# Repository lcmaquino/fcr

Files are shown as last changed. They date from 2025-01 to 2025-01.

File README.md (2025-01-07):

## Description

The Fenix Reballing Controller (FCR) software controls the temperature of two heating devices for preheating electronic boards or reballing BGA components. Examples of heating devices include an electric grill or an electric resistor. Due to the high electrical current required to power these devices, they should be activated via a mechanical relay or a solid-state relay.

The FCR consists of an electronic circuit with the [Raspberry Pi Pico](https://projects.raspberrypi.org/en/projects/getting-started-with-the-pico) microcontroller and a set of codes written for [MicroPython](https://www.micropython.org/).

## Assembly and Installation

  - Assemble the electronic circuit according to the schematic diagram: [fenix-controlador-de-ressolda.pdf](https://github.com/lcmaquino/fcr/tree/main/pcb/fenix-controlador-de-ressolda.pdf). Also, see the [simple wiring diagram](assets/fcr-simple-wiring.png);
  - Connect the relay input pins to the connectors indicated in the diagram by `OUT1` and `OUT2`;
  - Connect the relay output pins to the heating devices;
  - Connect the HD44780 LCD 16×02, MAX6675, and Keyes_AD_Key modules to their respective connectors indicated in the diagram;
  - Install the [MicroPython firmware](https://projects.raspberrypi.org/en/projects/getting-started-with-the-pico/3) on the Raspberry Pi Pico;
  - Use your preferred IDE to copy all files from the [`src`](https://github.com/lcmaquino/fcr/tree/main/src) directory to the Raspberry Pi Pico. (For example, you can use [Thonny](https://thonny.org/) or [Visual Studio Code](https://code.visualstudio.com/));
  - Power the electronic circuit with a 5V DC power supply with at least 500mA;

  The Keyes_AD_Key module has five tactile switches labeled SW1, SW2, SW3, SW4, and SW5. The FCR maps these switches for menu navigation such that:

  - SW1 - moves the menu to the left;
  - SW2 - increases the value of the currently displayed option;
  - SW3 - decreases the value of the currently displayed option;
  - SW4 - moves the menu to the right;
  - SW5 - selects the current menu;

## Usage

  The FCR has three modes:
  - Preheater - for preheating an electronic board;
  - Reballing - for reballing BGA components;
  - Auto Tuning - to automatically calculate the coefficients used in the [PID](https://en.wikipedia.org/wiki/Proportional-integral-derivative_controller) control;

  All modes have a menu containing specific and general options.

  The general options are:
  - `Kp` - proportional coefficient of the PID control;
  - `Ki` - integral coefficient of the PID control;
  - `Kd` - derivative coefficient of the PID control;
  - `ap` - actuation period is the period (in seconds) at which the PID control is updated;
  - `Run` - execute the mode functions;
  - `Home` - return to the initial mode selection screen;

  See below the specific options for each mode.

### Preheater Mode

  The Preheater mode controls only one heating device that should be placed below the electronic board.

  In Preheater mode, the specific options are:
  - `SV` - Setpoint Variable is the temperature (in degrees Celsius) that the heating element should reach;
  - `d` - duration is the duration (in seconds) the mode should run;

### Reballing Mode

  The Reballing mode controls two heating devices, one of which should be placed below the electronic board and the other above it.

  In Reballing mode, the specific options are:
  - `PTN` - pattern is the temperature pattern (in degrees Celsius) that the heating devices should follow. Each pattern consists of up to five parts, each containing the `r`, `L`, and `d` options explained below;
  - `r` - rate is the rate of temperature change (in degrees Celsius per second);
  - `L` - limit is the temperature limit (in degrees Celsius) that should be reached;
  - `d` - duration is the duration (in seconds) that the temperature should remain at its limit `L`;

  Up to 10 temperature patterns can be configured. Here is an example configuration:
```
  PTN1
  | - r1: 0.86
  | - L1: 120.0
  | - d1: 60
  | - r2: 0.57
  | - L2: 180.0
  | - d2: 60
  | - r3: 0.29
  | - L3: 210.0
  | - d3: 60
  | - r4: 0.19
  | - L4: 227.0
  | - d4: 60
  | - r5: 0.0
  | - L5: 0.0
  | - d5: 0
```

  Note that in this example, the PTN1 pattern will have four active parts. The fifth part is all zeros and will be ignored by the FCR. The figure below represents this pattern.

  Image of the graph representing the PTN1 pattern

  In the first part of the pattern, the temperature should rise at a rate of `r1 = 0.86`°C/s until it reaches `L1 = 120`°C, staying at this temperature for `d1 = 60`s. In the second part, the temperature should rise at a rate of `r2 = 0.57`°C/s until it reaches `L2 = 180`°C, staying at this temperature for `d2 = 60`s. In the third part, the temperature should rise at a rate of `r3 = 0.29`°C/s until it reaches `L3 = 210`°C, staying at this temperature for `d3 = 60`s. Finally, in the fourth part, the temperature should rise at a rate of `r4 = 0.19`°C/s until it reaches `L4 = 227`°C, staying at this temperature for `d4 = 60`s.

### Auto Tuning

  The Auto Tuning mode analyzes the temperature data of the heating device below the electronic board to approximately calculate the `Kp`, `Ki`, and `Kd` coefficients of the PID controller.

  In Auto Tuning mode, the specific options are:
  - `SV` - Setpoint Variable is the temperature (in degrees Celsius) that the heating element should reach;
  - `d` - duration is the duration (in seconds) the mode should run;

## License

FCR is open-sourced software licensed under the [GPL v3.0 or later](https://github.com/lcmaquino/ccolab/blob/main/LICENSE).

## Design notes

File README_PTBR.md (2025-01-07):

## Descrição

O programa Fenix Controlador de Ressolda (FCR) controla a temperatura de dois
dispositivos de aquecimento para a realização de pré-aquecimento de placas 
eletrônicas ou para a ressoldagem de componentes BGA. Como exemplo de 
dispositivo de aquecimento pode-se citar uma churrasqueira elétrica ou 
uma resitência elétrica. Devido a alta corrente elétrica necessária para 
ligar esses dispositivos, eles devem ser acionados via um relê mecânico 
ou um relê de estado sólido.

O FCR é composto por um circuito eletrônico com o microcontrolador
[Raspberry Pi Pico](https://projects.raspberrypi.org/en/projects/getting-started-with-the-pico)
e por um conjunto de códigos escritos para [MicroPython](https://www.micropython.org/).

## Montagem e Instalação

  - Monte o circuito eletrônico conforme o diagrama esquemático:
  [fenix-controlador-de-ressolda.pdf](https://github.com/lcmaquino/fcr/tree/main/pcb/fenix-controlador-de-ressolda.pdf).
  Veja também o [diagrama simplificado](assets/fcr-simple-wiring.png) de ligação;
  - Conecte os pinos de entrada do relê nos conectores indicados no diagrama 
  por `OUT1` e `OUT2`;
  - Conecte os pinos de saída do relê nos dispositivos de aquecimento;
  - Conecte os módulos HD44780 LCD 16×02, MAX6675 e Keyes_AD_Key nos seus respectivos
    conectores indicados no diagrama;
  - Instale o [firmware do MicroPython](https://projects.raspberrypi.org/en/projects/getting-started-with-the-pico/3) 
  no Raspberry Pi Pico;
  - Utilize a sua IDE preferida para copiar todos os arquivos do diretório 
  [`src`](https://github.com/lcmaquino/fcr/tree/main/src) para o Raspberry Pi Pico.
  (Por exemplo, você pode usar o [Thonny](https://thonny.org/) ou o 
  [Visual Studio Code](https://code.visualstudio.com/));
  - Ligue o circuito eletrônico com uma fonte de alimentação de 5V DC e 
  pelo menos 500mA;

  O módulo Keyes_AD_Key possui cinco chaves tácteis rotuladas como SW1, SW2, 
  SW3, SW4 e SW5. O FCR faz o mapeamento dessas chaves para a navegação 
  dos menus de modo que:

  - SW1 - movimenta o menu para a esquerda;
  - SW2 - aumenta o valor da opção exibida no momento;
  - SW3 - diminui o valor da opção exibida no momento;
  - SW4 - movimenta o menu para a direita;
  - SW5 - seleciona o menu atual;

## Uso

  O FCR possui três modos:
  - Preheater - para realizar o pré-aquecimento de uma placa eletrônica;
  - Reballing - para realizar a ressolda de componentes BGA;
  - Auto Tuning - para calcular automaticamente os parâmetros usados no controle
  [PID](https://pt.wikipedia.org/wiki/Controlador_proporcional_integral_derivativo);

  Todos os modos possuem um menu que contém opções específicas e opções gerais.

  As opções gerais são:
  - `Kp` - coeficiente proporcional do controle PID;
  - `Ki` - coeficiente integral do controle PID;
  - `Kd` - coeficiente derivativo do controle PID;
  - `ap` - _actuation period_ é o período (em segundos) no qual o controle PID é atualizado;
  - `Run` - executar as funções do modo;
  - `Home` - voltar para a tela inicial de seleção de modo;

  Vide a seguir as opções específicas de cada modo.

### Modo Preheater

  O modo Preheater controla apenas um dispositivo de aquecimento que deve ser 
  posicionado abaixo da placa eletrônica.

  No modo Preheater as opções específicas são:
  - `SV` - _Setpoint Variable_ é a temperatura (em graus Celcius) que o 
    elemento de aquecimento deve atingir;
  - `d` - _duration_ é a duração (em segundos) que o modo deve ficar executando;

### Modo Reballing

  O modo Reballing controla dois dispositivos de aquecimento sendo que 
  um deles deve ser posicionado abaixo da placa eletrônica e o outro
  acima dela.

  No modo Reballing as opções específicas são:
  - `PTN` - _pattern_ é o padrão de temperatura (em graus Celcius) 
    que os dispositivos de aquecimento devem seguir. Cada padrão é composto por até cinco 
    partes, sendo que cada uma delas contém as opções `r`, `L` e `d` explicadas a seguir;
  - `r` - _rate_ é a taxa de variação da temperatura (em graus Celcius por segundo);
  - `L` - _limit_ é o valor limite que a temperatura (em graus Celcius) deve atingir;
  - `d` - _duration_ é a duração (em segundos) que a temperatura deve permanecer no seu limite `L`;

  É possível configurar até 10 padrões de temperatura. Veja um exemplo de configuração a seguir:
```
  PTN1
  | - r1: 0.86
  | - L1: 120.0
  | - d1: 60
  | - r2: 0.57
  | - L2: 180.0
  | - d2: 60
  | - r3: 0.29
  | - L3: 210.0
  | - d3: 60
  | - r4: 0.19
  | - L4: 227.0
  | - d4: 60
  | - r5: 0.0
  | - L5: 0.0
  | - d5: 0
```

  Note que nesse exemplo o padrão PTN1 terá quatro partes ativas. A quinta parte
  está toda nula e será ignorada pelo FCR. A figura a seguir representa esse padrão.

  Imagem do gráfico representando o padrão PTN1

  Na primeira parte do padrão a temperatura deverá
  subir com uma taxa de variação de `r1 = 0.86`°C/s até atingir `L1 = 120`°C, 
  ficando nessa temperatura por `d1 = 60`s. Na segunda parte a temperatura deverá
  subir com uma taxa de variação de `r2 = 0.57`°C/s até atingir `L2 = 180`°C, 
  ficando nessa temperatura por `d2 = 60`s. Já na terceira parte a temperatura 
  deverá subir com uma taxa de variação de `r3 = 0.29`°C/s até atingir `L3 = 210`°C, 
  ficando nessa temperatura por `d3 = 60`s. Por fim, na quarta parte a temperatura 
  deverá subir com uma taxa de variação de `r4 = 0.19`°C/s até atingir `L4 = 227`°C, 
  ficando nessa temperatura por `d4 = 60`s.

### Auto Tuning

  O modo Auto Tuning analisa os dados de temperatura do dispostivo de aquecimento 
  abaixo da placa eletrônica para calcular de modo aproximado os coeficientes
  `Kp`, `Ki` e `Kd` do controlador PID.

  No modo Auto Tuning as opções específicas são:
  - `SV` - _Setpoint Variable_ é a temperatura (em graus Celcius) que o 
    elemento de aquecimento deve atingir;
  - `d` - _duration_ é a duração (em segundos) que o modo deve ficar executando;

## Licença

FCR é um programa de código aberto sob a licença [GPL v3.0 ou posterior](https://github.com/lcmaquino/ccolab/blob/main/LICENSE).

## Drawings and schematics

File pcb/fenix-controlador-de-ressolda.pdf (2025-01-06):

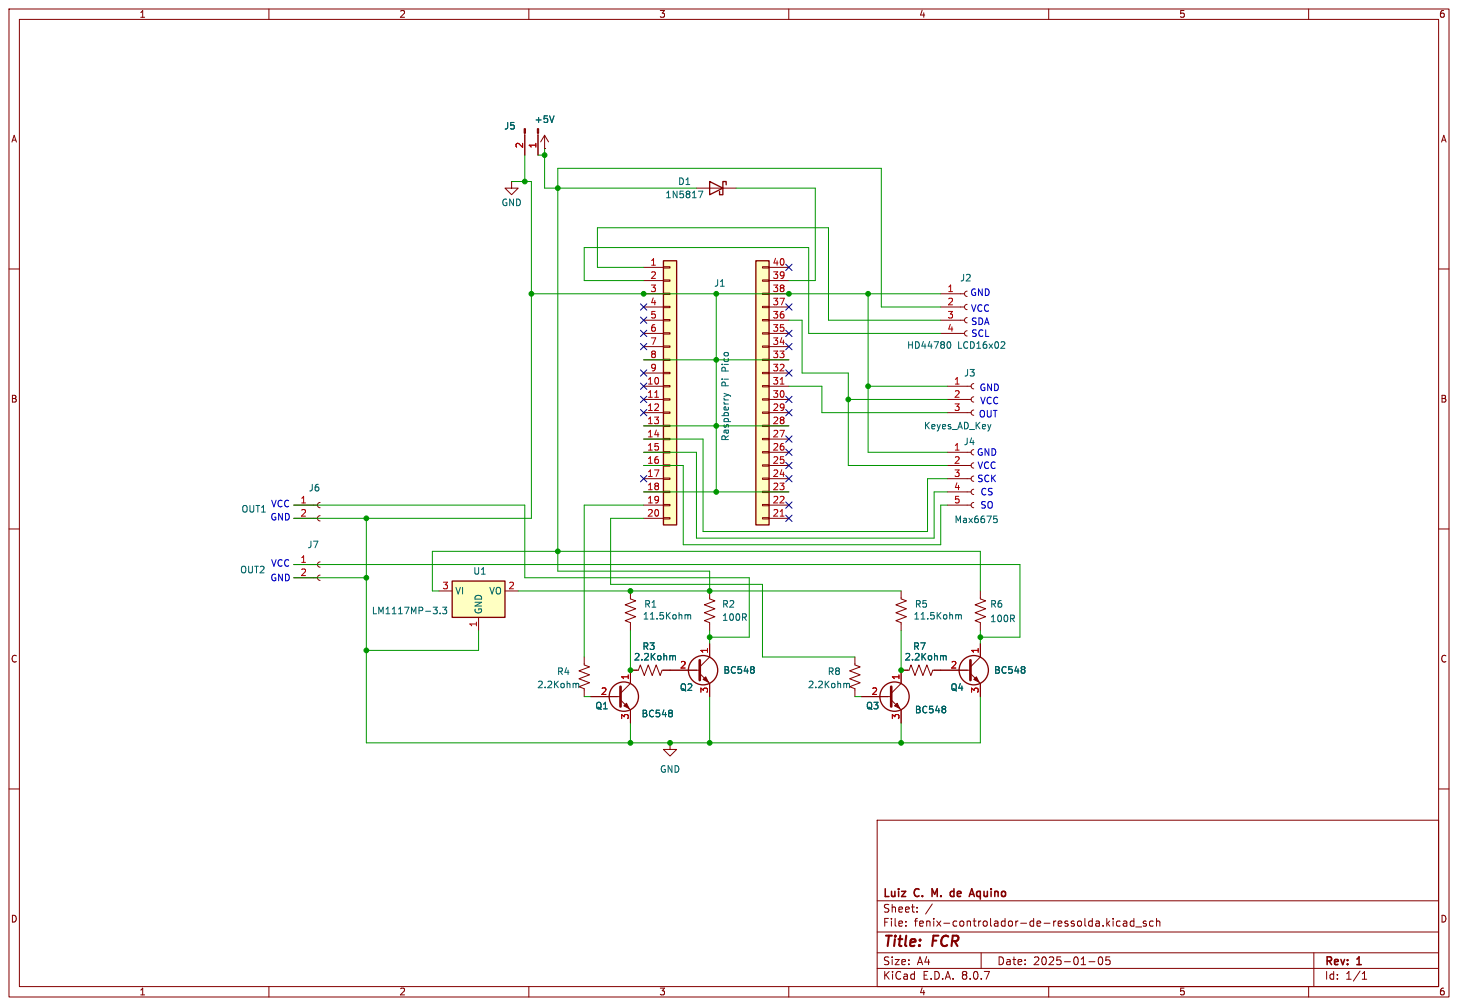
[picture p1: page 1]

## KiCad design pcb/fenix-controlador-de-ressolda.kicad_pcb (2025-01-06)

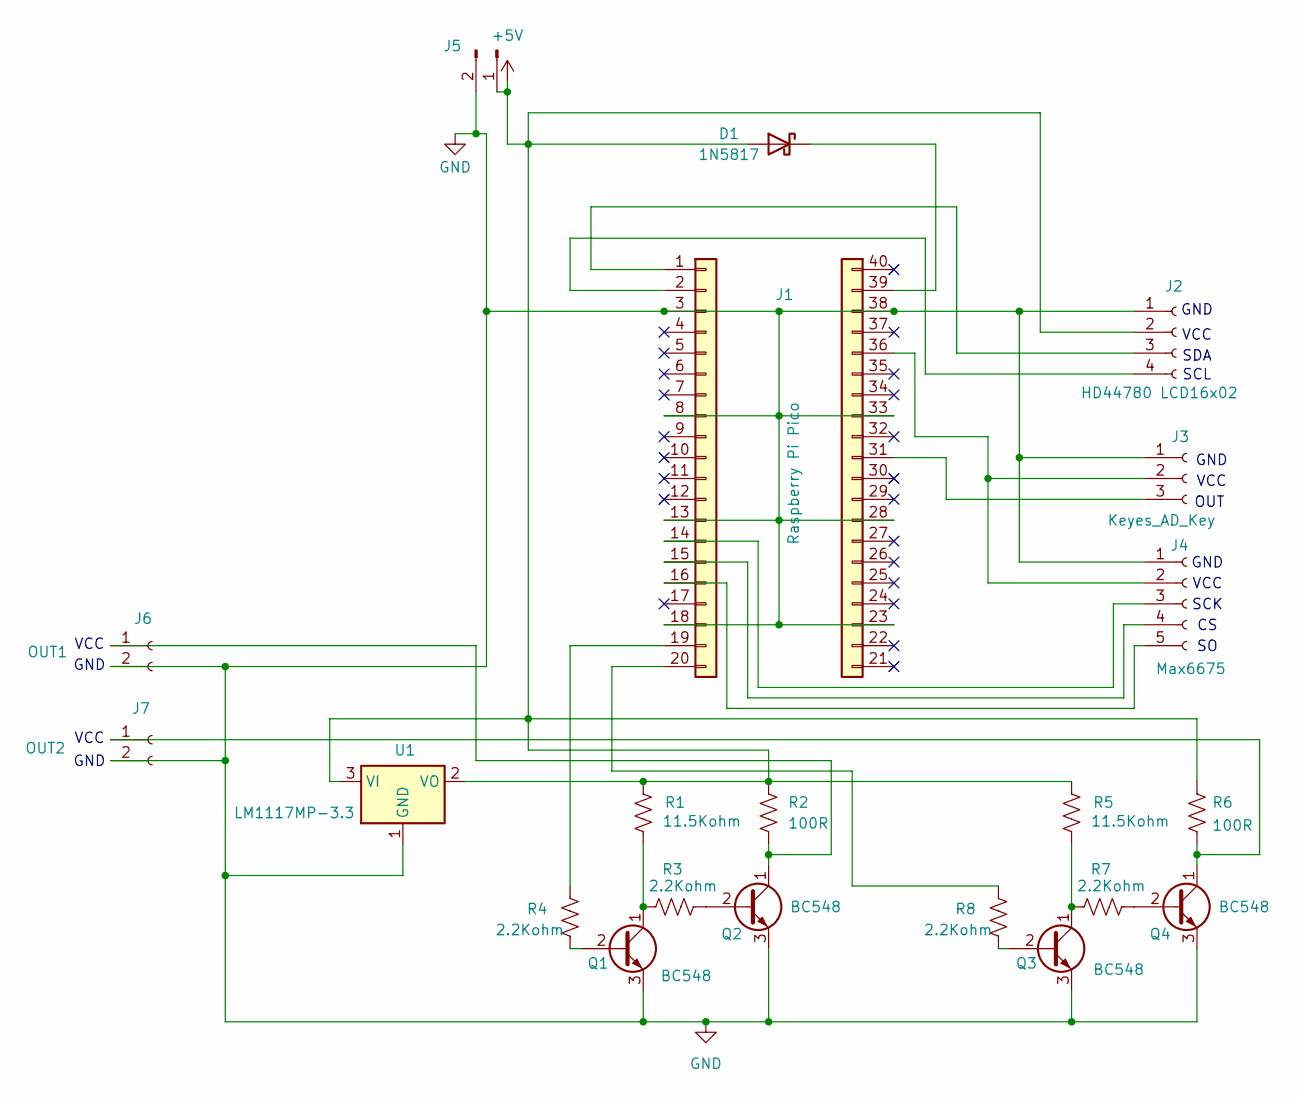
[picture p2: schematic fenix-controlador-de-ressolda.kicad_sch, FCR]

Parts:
D1: 1N5817; D_DO-41_SOD81_P10.16mm_Horizontal
J1: Raspberry Pi Pico; PinSocket_1x20_P2.54mm_Vertical
J2: HD44780 LCD16x02; PinSocket_1x04_P2.54mm_Vertical
J3: Keyes_AD_Key; PinSocket_1x03_P2.54mm_Vertical
J4: Max6675; PinSocket_1x05_P2.54mm_Vertical
J5: Conn_01x02_Pin; PinHeader_1x02_P2.54mm_Vertical
J6: OUT1; PinSocket_1x02_P2.54mm_Vertical
J7: OUT2; PinSocket_1x02_P2.54mm_Vertical
J9: Conn_01x20; PinSocket_1x20_P2.54mm_Vertical
Q1, Q2, Q3, Q4: BC548; TO-92_Inline
R1, R5: 11.5Kohm; R_Axial_DIN0207_L6.3mm_D2.5mm_P7.62mm_Horizontal
R2, R6: 100R; R_Axial_DIN0207_L6.3mm_D2.5mm_P7.62mm_Horizontal
R3, R4, R7, R8: 2.2Kohm; R_Axial_DIN0207_L6.3mm_D2.5mm_P7.62mm_Horizontal
U1: LM1117MP-3.3; SOT-223-3_TabPin2

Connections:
GND: J1.3, J1.8, J1.13, J1.18, J2.1, J3.1, J4.1, J5.2, J6.2, J7.2, J9.23, J9.28, J9.33, J9.38, Q1.3 (E), Q2.3 (E), Q3.3 (E), Q4.3 (E), U1.1 (GND)
unnamed: D1.1 (K), J9.39
unnamed: J1.1, J2.3
unnamed: J1.2, J2.4
unnamed: J1.14, J4.3
unnamed: J1.15, J4.4
unnamed: J1.16, J4.5
unnamed: J1.19, R4.1
unnamed: J1.20, R8.1
unnamed: J3.2, J4.2, J9.36
unnamed: J3.3, J9.31
unnamed: J6.1, Q2.1 (C), R2.2
unnamed: J7.1, Q4.1 (C), R6.2
unnamed: Q1.2 (B), R4.2
unnamed: Q1.1 (C), R1.2, R3.1
unnamed: Q2.2 (B), R3.2
unnamed: Q3.2 (B), R8.2
unnamed: Q3.1 (C), R5.2, R7.1
unnamed: Q4.2 (B), R7.2

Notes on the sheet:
VCC
GND
SDA
SCK
SCL
OUT

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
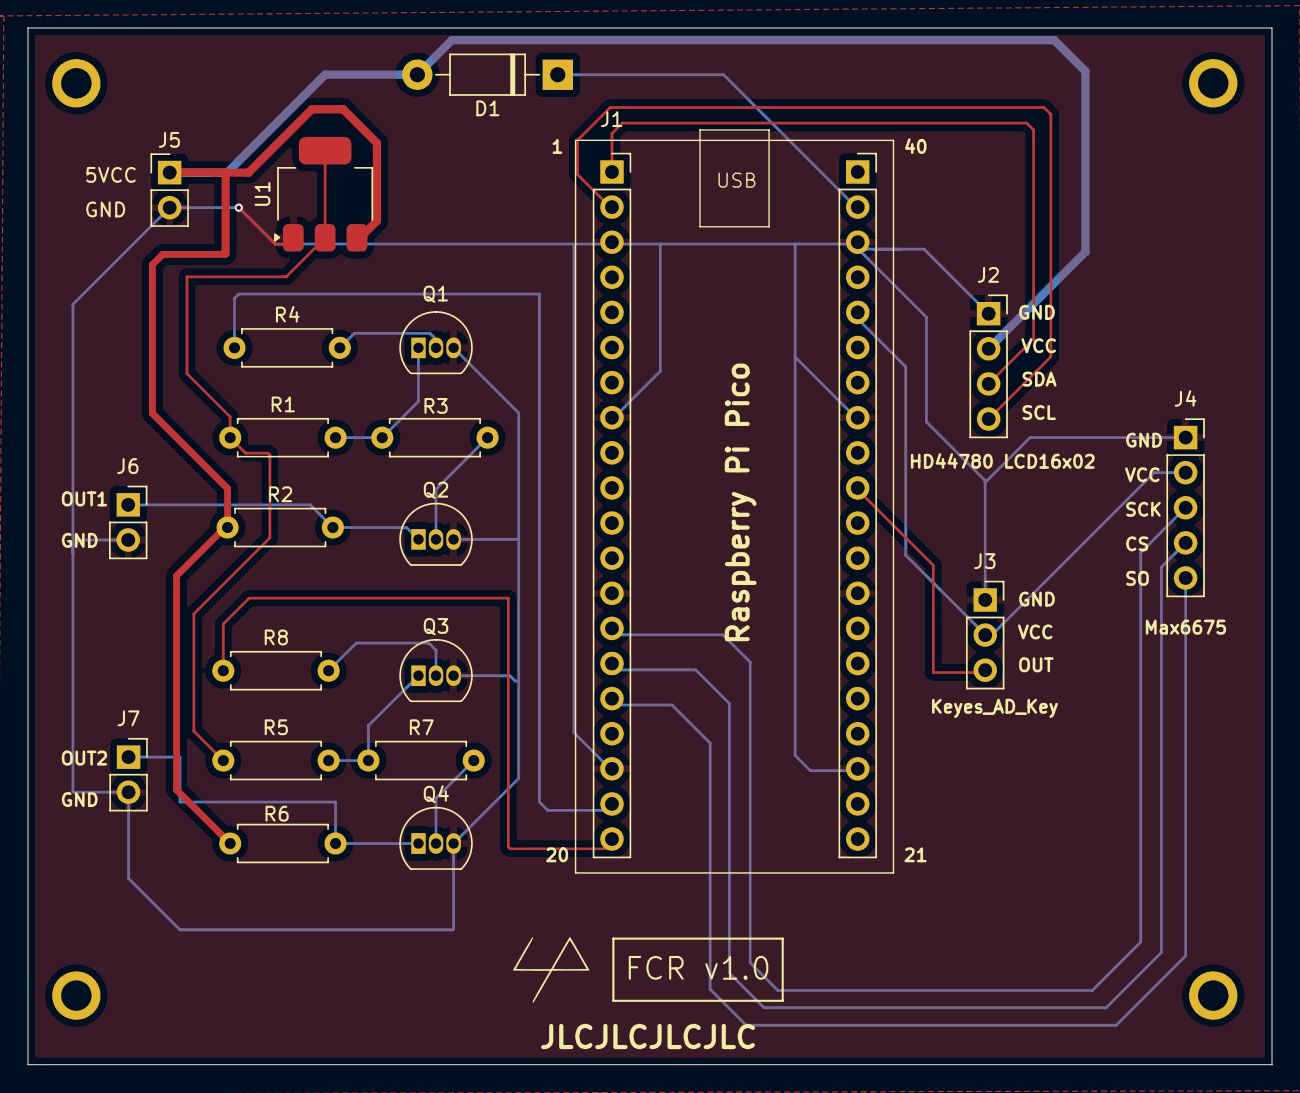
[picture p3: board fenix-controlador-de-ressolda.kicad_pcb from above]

Board: 4 copper layers, 90.0 x 75.0 mm, 22 parts (0 on the bottom side), 21 nets.

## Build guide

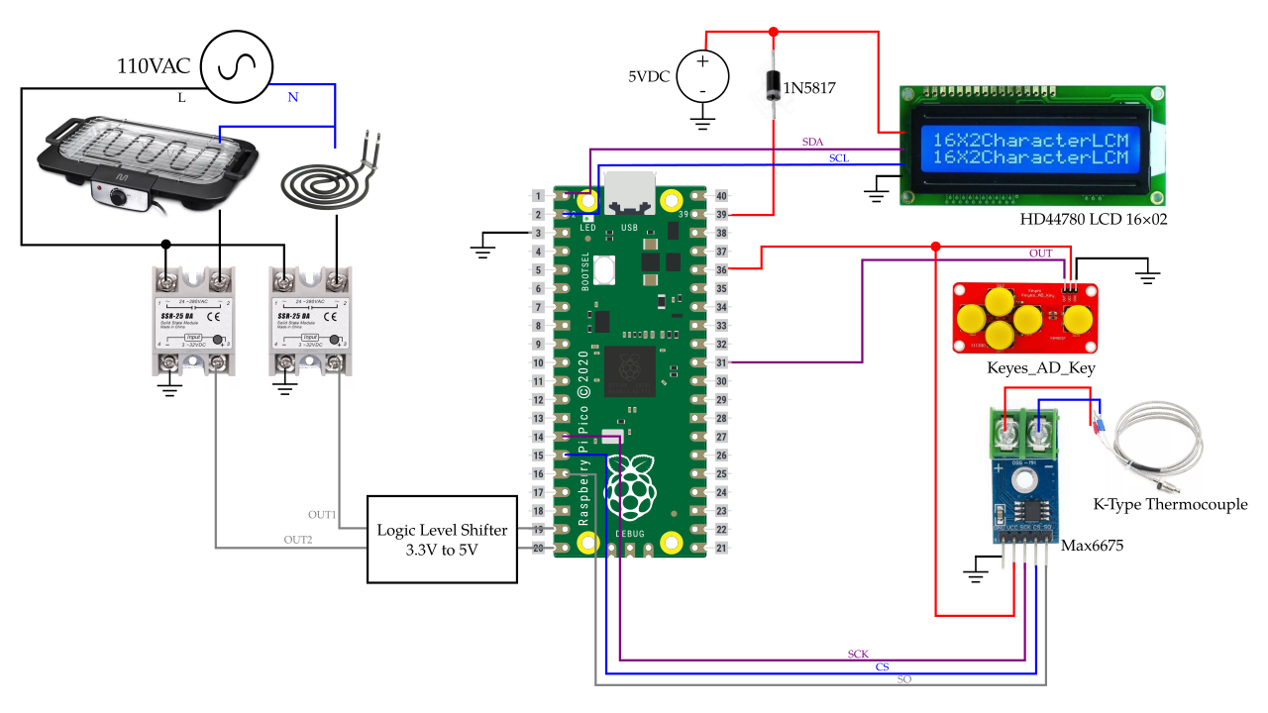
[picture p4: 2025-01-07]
assets/fcr-simple-wiring.png

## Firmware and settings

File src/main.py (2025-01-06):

"""
 * Copyright (c) 2025 Luiz C. M. de Aquino <aquino.luizclaudio@gmail.com>
 *
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
import time
from machine import ADC, Pin, I2C
from utils.keyesadkey import KeyesADKey
from utils.i2c_lcd import I2cLcd
from mode.preheater import Preheater
from mode.reballing import Reballing
from mode.tuning import Tuning

# Comunicate with HD44780 LCD connected via I2C.
I2C_ADDR = 0x27
I2C_NUM_ROWS = 2
I2C_NUM_COLS = 16

i2c = I2C(0, sda=Pin(0), scl=Pin(1), freq=400000)
lcd = I2cLcd(i2c, I2C_ADDR, I2C_NUM_ROWS, I2C_NUM_COLS)
lcd.clear()

# Connect to channel 0 (GP26)
adc = ADC(0)
keyboard = KeyesADKey(adc)

models = [
  Preheater("Preheater", "/config/preheater.json"),
  Reballing("Reballing", "/config/reballing.json"),
  Tuning("Auto Tuning", "/config/tuning.json")
]

currentModel = 0
modelsCount = len(models)
lastKey = -1.0
lcd.clear()
i = 0
while True:
  key = keyboard.read()

  if models[currentModel].isLocked():
    if key == keyboard.LEFT:
      models[currentModel].previousMenu()

    if key == keyboard.RIGHT:
      models[currentModel].nextMenu()

    if key == keyboard.UP:
      models[currentModel].increaseParameter()
      
    if key == keyboard.DOWN:
      models[currentModel].decreaseParameter()

    if key == keyboard.SELECT and lastKey != keyboard.SELECT:
      label = models[currentModel].menuLabel()
      if label == "Home":
        models[currentModel].stop()
        models[currentModel].unlock()

      if label == "Run":
        if models[currentModel].isRunning():
          models[currentModel].stop()
        else:
          models[currentModel].run()

      if label != "Home" and label != "Run":
        models[currentModel].stop()
    else:
      if models[currentModel].isRunning():
        models[currentModel].run()
  else:
    if key == keyboard.LEFT:
        currentModel = (currentModel - 1)%modelsCount

    if key == keyboard.RIGHT:
        currentModel = (currentModel + 1)%modelsCount

    if key == keyboard.SELECT and lastKey != keyboard.LONG_SELECT:
      models[currentModel].lock()

  lines = models[currentModel].view()

  lastKey = key
  lcd.move_to(0, 0)
  lcd.putstr(lines[0])
  lcd.move_to(0, 1)
  lcd.putstr(lines[1])
 
  time.sleep(1.0/60)

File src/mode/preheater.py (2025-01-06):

"""
 * Copyright (c) 2025 Luiz C. M. de Aquino <aquino.luizclaudio@gmail.com>
 *
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
import time
from machine import Pin
from mode.mode import Mode
from utils.max6675 import MAX6675
from utils.pid import PID

class Preheater(Mode):
  """
    Implements the Preheater Mode to control the temperature of one heater element.
    That heater must be connected to a mechanical relay or to a 
    State Solid Relay (SSR).
  """
  def __init__(self, name = "", filename = ""):
    super().__init__(name, filename)

    self._bottomHeaterTemperature = MAX6675(
      Pin(10, Pin.OUT), 
      Pin(11, Pin.OUT), 
      Pin(12, Pin.IN)
    )
    
    self.bottomHeaterRelay= Pin(15, Pin.OUT)
    self.bottomHeaterRelay.low()
    self._heaterPID = PID(
      Kp = self.getValue("Kp"),
      Ki = self.getValue("Ki"),
      Kd = self.getValue("Kd"),
    )
    self.stopAt = 0
    self.PV = 0.0
    # self.DEBUG = True

  def view(self):
    if self.isLocked():
      label = self.menuLabel()
      
      if label == "Run" or label == "Home":
        line1 = label
      else:
        value = self.getValue(label)
        info = self.menuInfo(label)
        unit = info["unit"]
        if len(unit) > 0 and unit[0] == "C":
          unit = "\xDF" + unit

      if label == "SV" or label == "Kp":
        line1 = label + " " + f"{value:5.1f}{unit}"

      if label == "Ki" or label == "Kd":
        line1 = label + " " + f"{value:6.3f}{unit}"

      if label == "ap":
        line1 = label + " " + f"{value:4.1f}{unit}"
        
      if label == "d":
        line1 = label + " " + f"{value:03d}{unit}"

      if self.isRunning():
        line0 = self.fill(f"PV {self.PV:5.1f}\xDFC", f"{self.display(self.getValue('d') - round(self._duration/1000.0))}")
        line1 = self.fill(line1, "[*]")
      else:
        line0 = self.fill(self.name(), "")
        line1 = self.fill(line1, "[>]")
    else:
      line0 = self.fill("Mode", "")
      line1 = self.fill(self.name(), "")
      
    self._lines = [
      line0,
      line1
    ]

    return self._lines

  def run(self):
    self.PV = self._bottomHeaterTemperature.read()
        
    if not self._isRunning:
      self.startRunning = time.ticks_ms()
      self.firstPV = self.PV
      self.SV = self.getValue("SV")
      self.samplePeriod = 1000.0*self.getValue("ap")
      self.runningPeriod = self.getValue("d")
      self.stopAt = time.ticks_add(self.startRunning, round(self.samplePeriod))
      self.Kp = self.getValue("Kp")
      self._heaterPID.start(self.PV)
      self._heaterPID.coefficients(
        self.Kp,
        self.getValue("Ki"),
        self.getValue("Kd")
      )
      self.lastTime = self.startRunning
      self._duration = 0.0
      self.save()
      self._menuID = 0
      self._isRunning = True
      factor = 1.0

      if self.DEBUG:
        print(f"t;PV;SV;FACTOR;u")
        print(f"{0.0};{self.PV};{self.PV};{factor};0.0")

    now = time.ticks_ms()
    dt = time.ticks_diff(now, self.lastTime)/1000.0
    self._duration = time.ticks_diff(now, self.startRunning)

    if time.ticks_diff(now, self.lastTime) > self.samplePeriod:
      self.u = self._heaterPID.control(self.PV, self.SV, dt)
      self.lastTime = now

      #Calculate actuation period
      factor = 1 - (0.05)**(-self.u/(self.Kp*(-self.SV + self.firstPV)))
      if factor < 0.0:
        factor = 0.0

      self.stopAt = time.ticks_add(now, round(factor*self.samplePeriod))

      if self.DEBUG:
        print(f"{self._duration/1000.0};{self.PV};{self.SV};{factor};{self.u}")

    if time.ticks_diff(self.stopAt, now) > 0:
      self.bottomHeaterRelay.high()
    else:
      self.bottomHeaterRelay.low()

    if self._duration > 1000.0*self.runningPeriod:
      self.stop()

  def stop(self):
    self._isRunning = False
    self.save()
    self.bottomHeaterRelay.low()

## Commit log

2025-01-06 Let the fun begin!
    [fenix-controlador-de-ressolda-B_Mask.gbs, fenix-controlador-de-ressolda-B_Paste.gbp, fenix-controlador-de-ressolda-B_Silkscreen.gbo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]
2025-01-07 Add a simple wiring diagram.

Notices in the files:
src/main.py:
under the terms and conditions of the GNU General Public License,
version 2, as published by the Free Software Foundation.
